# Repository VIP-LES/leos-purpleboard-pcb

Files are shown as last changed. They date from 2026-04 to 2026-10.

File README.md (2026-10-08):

# LEOS Purpleboard

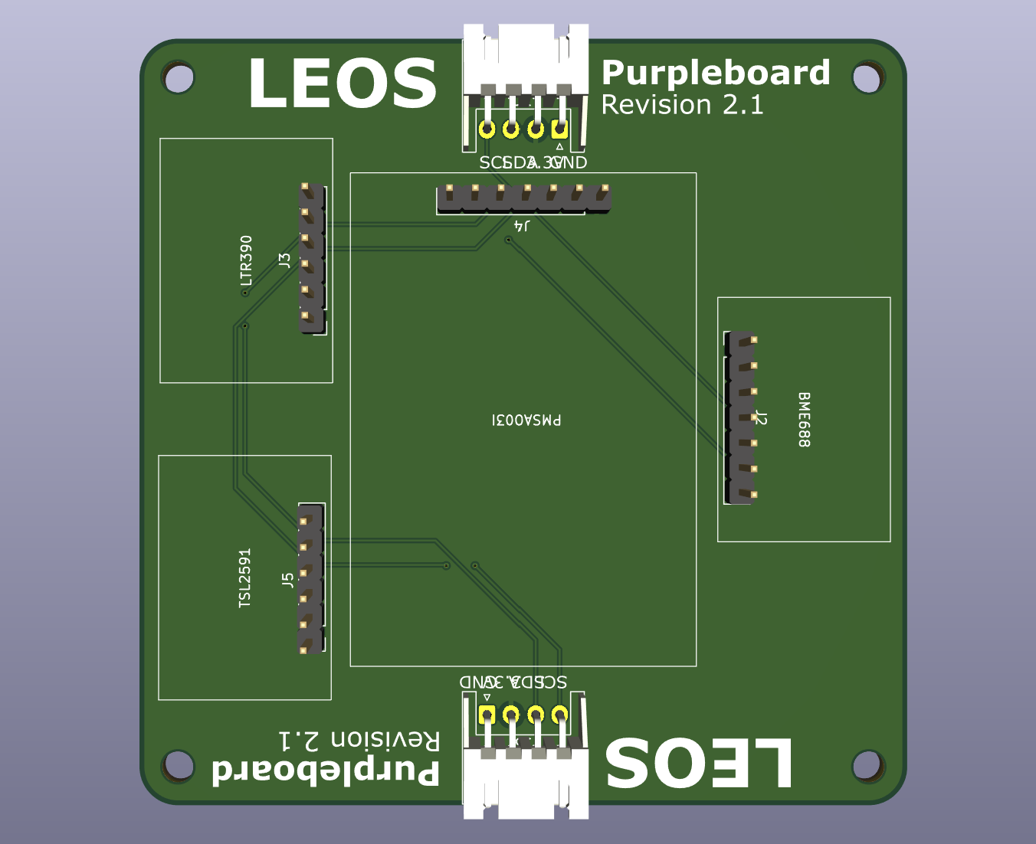
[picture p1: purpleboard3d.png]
3D render of the LEOS Purpleboard


The Purpleboard holds four environmental and light sensor breakout boards on a shared I²C bus, powered at 3.3 V. The board has no microcontroller: it connects to a host board through a JST XH cable, and a second JST XH connector passes the I²C bus and power through to another board.

**Current revision:** 2.1

## Sensors

| Ref | Sensor | Measures | Header | Default I²C address |
|-----|---|---|---|---|
| J2 | BME688 | Temperature, humidity, pressure, gas | 7-pin | 0x77 |
| J3 | LTR390 | UV and ambient light | 6-pin | 0x53 |
| J4 | PMSA003I | Air Quality (PM1.0, PM2.5, PM10) | 7-pin | 0x12 |
| J5 | TSL2591 | High-dynamic-range light | 6-pin | 0x29 |

Each sensor is a breakout board that plugs into a pin header. All four share the same SCL and SDA lines, and their default addresses do not conflict.

## Connectors

| Pin | Signal |
|-----|---|
| 1 | GND |
| 2 | +3.3 V |
| 3 | SDA |
| 4 | SCL |

## Sensor header wiring

- **VIN** on every header is connected to +3.3 V, and **GND** to ground.
- **SCL/SDA** are connected to the shared I²C bus. On the BME688 these are the SCK and SDI pins.
- Not connected: the 3V output pins on all breakouts, BME688 SDO and CS, LTR390 INT, TSL2591 INT, and PMSA003I RST and SET.

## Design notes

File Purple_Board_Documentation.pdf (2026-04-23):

# Purple Board - LEOS Spring 2026

### Project Documentation

Contributed Members: Cambron Berry, Yash Ghanate, Yuchan Ahn
Launch Date: April 18th

## Components

The Purple Board is equipped with the following sensors for environmental data acquisition:

Sensor Type | Model
Air Quality Sensor | PMSA003I
UV Sensor | LTR 390
Light Sensor | TSL 2519
Gas Sensor | BME 688

## Assembly Process

Planning
Before beginning initial digital design in KiCad, the hardware architecture team sought out new sensors to improve the board's ability to acquire more precise data. Cam, Yash, and I (Yuchan) researched prospective sensor models capable of handling the tasks the team initially intended.

Designing
With the selected components confirmed for the Purple Board, Cam, Yash, and I were assigned to develop the initial schematics and carry the design through to completion. Using a matching number of pin-headers, we successfully designed a schematic that had a few warnings but zero errors that could have prevented data acquisition.

After the schematic was finalized, we moved into board routing. The routing process presented a significant challenge — without advanced routing experience, the initial results were messy and unorganized. We reached out to experienced members including Channing, Jenna, and Matthew for guidance, and with their input we were able to resolve the issues and produce a clean layout.

Assembly
In the first few weeks, the focus was on desoldering the old Purple Board to salvage any reusable components. Once desoldering was complete, the hardware architecture team began soldering the new board. The process started with pin-headers and was completed successfully without major issues.

Testing and Launch
Working alongside members from the Software Team, all sensors on the Purple Board were confirmed to be functioning as intended. The board was cleared for integration into the balloon platform and launched on April 18th.

During the launch, the Purple Board was gathering data correctly. However, due to an unknown error, the acquired data was not accessible after the flight.

## Takeaways & Next Steps

The following objectives have been identified for improvement in the next iteration:
- Reduce outliers and potential errors that may occur during testing or launch
- Ensure data is reliably stored and accessible after the launch
- Establish a data recovery protocol in case of unknown post-flight errors

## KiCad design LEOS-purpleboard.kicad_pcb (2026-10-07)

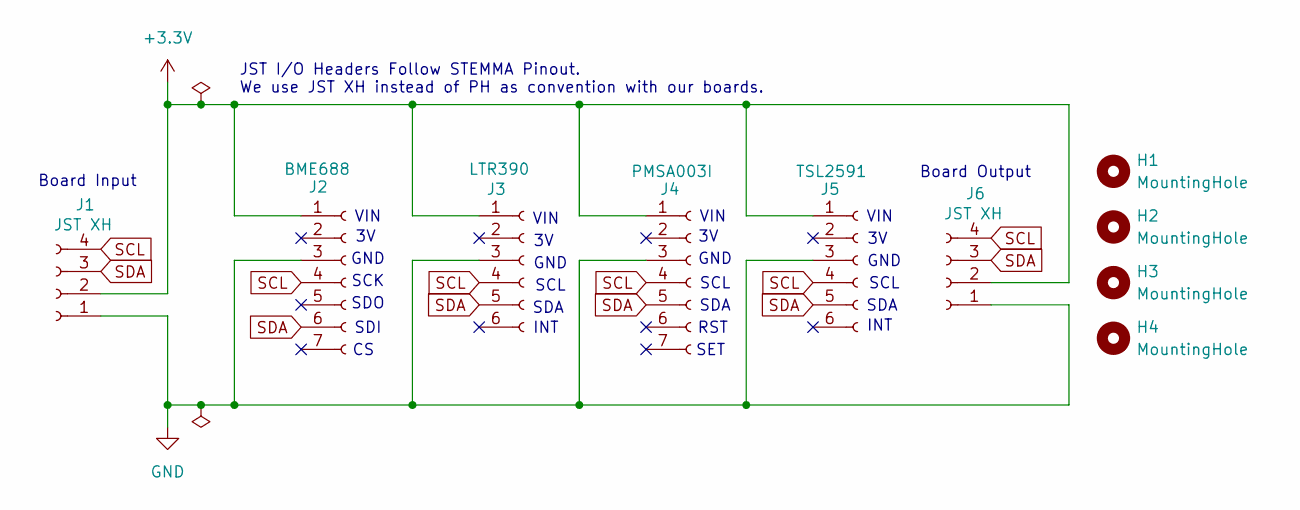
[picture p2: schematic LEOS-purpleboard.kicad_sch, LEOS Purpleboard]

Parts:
H1, H2, H3, H4: MountingHole; MountingHole_3.2mm_M3
J1, J6: JST XH; JST_XH_S4B-XH-A_1x04_P2.50mm_Horizontal
J2: BME688; PinHeader_1x07_P2.54mm_Vertical
J3: LTR390; PinHeader_1x06_P2.54mm_Vertical
J4: PMSA003I; PinHeader_1x07_P2.54mm_Vertical
J5: TSL2591; PinHeader_1x06_P2.54mm_Vertical

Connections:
+3.3V: J1.2, J2.1, J3.1, J4.1, J5.1, J6.2
GND: J1.1, J2.3, J3.3, J4.3, J5.3, J6.1
SCL: J1.4, J2.4, J3.4, J4.4, J5.4, J6.4
SDA: J1.3, J2.6, J3.5, J4.5, J5.5, J6.3

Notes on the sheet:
JST I/O Headers Follow STEMMA Pinout. We use JST XH instead of PH as convention with our boards.
SCK
GND
VIN
INT
SDI
SET
SDA
SDO
SCL
Board Output
Board Input
RST

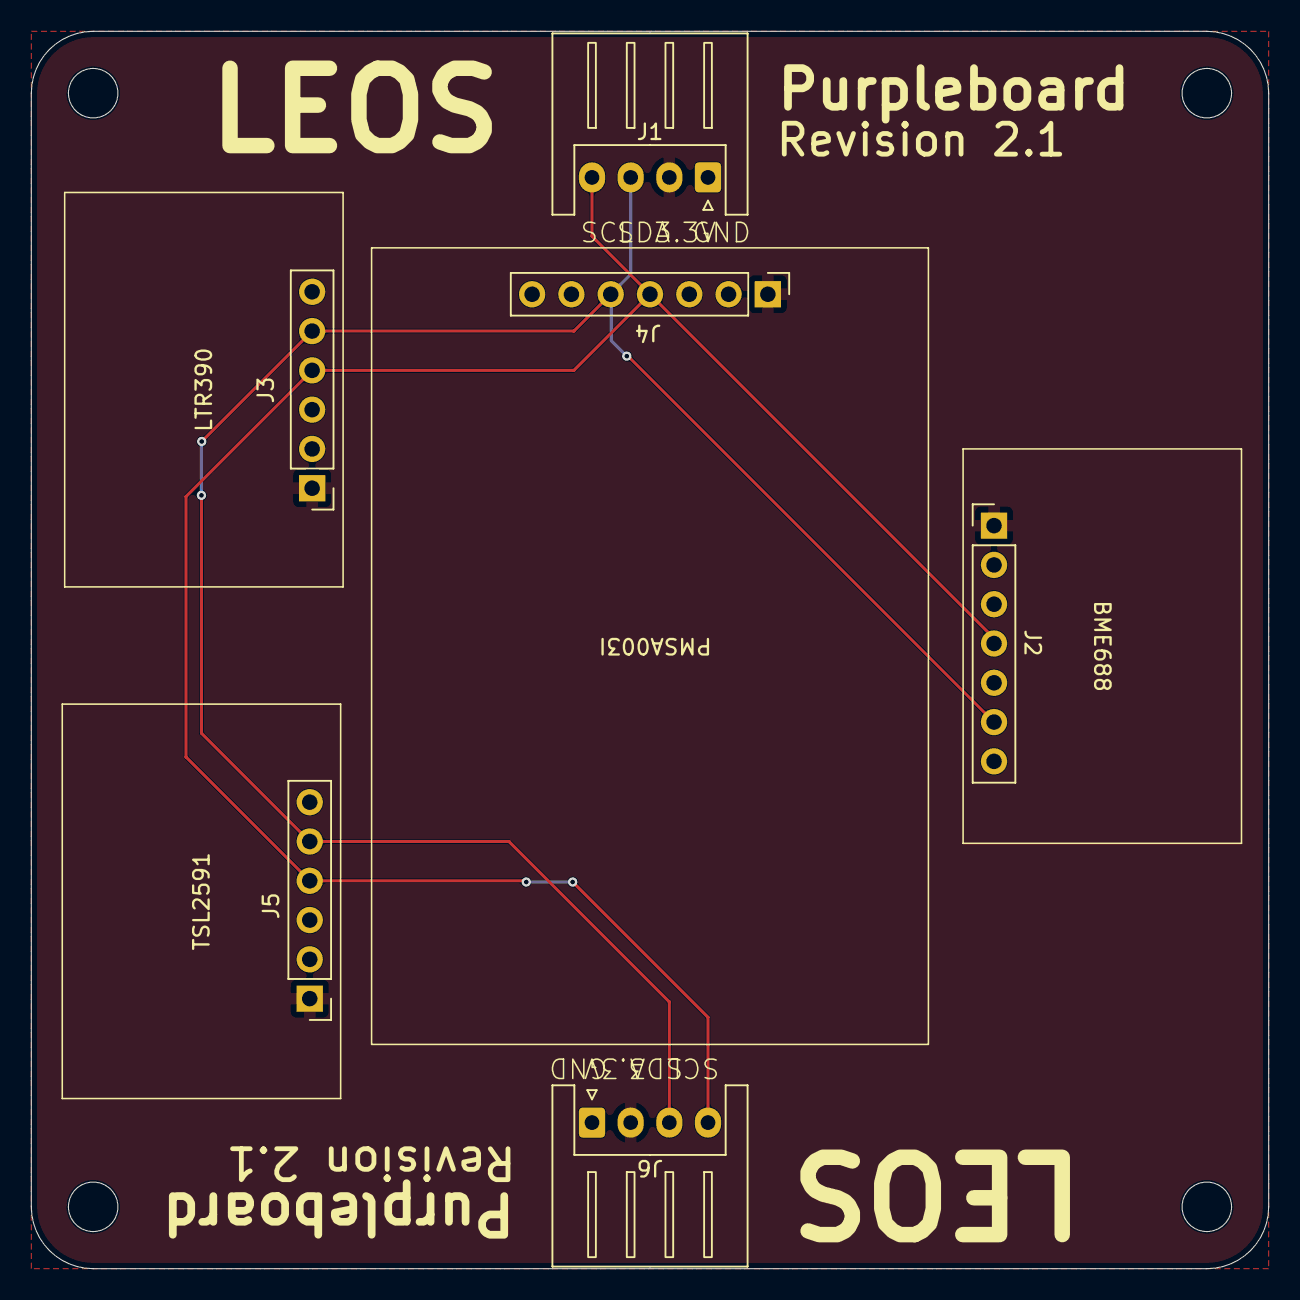
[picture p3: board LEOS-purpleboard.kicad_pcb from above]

Board: 2 copper layers, 80.0 x 80.0 mm, 10 parts (0 on the bottom side), 4 nets.

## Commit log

2026-02-13 Remove stack template
    [LEOS-stack-template.kicad_pcb, LEOS-stack-template.kicad_sch]
2026-02-13 Fix flipped pinouts, update 3D model, and redesign schematic
    [LEOS-purpleboard.kicad_pcb, LEOS-purpleboard.kicad_sch]
2026-02-17 Add production date to board.
    [LEOS-purpleboard.kicad_pcb, LEOS-purpleboard.kicad_sch]
2026-10-07 updated to kicad 10
    [LEOS-purpleboard.kicad_pcb]
2026-10-07 update to kicad 10
    [LEOS-purpleboard.kicad_sch]
